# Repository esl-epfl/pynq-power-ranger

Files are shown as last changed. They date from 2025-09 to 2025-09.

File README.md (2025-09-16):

<div align="center">
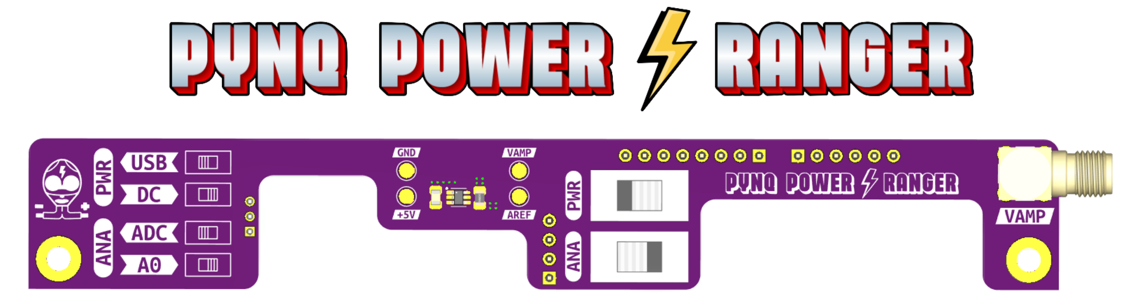
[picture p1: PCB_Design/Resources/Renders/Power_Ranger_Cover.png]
Power Ranger Board
    
</div>

## 🚀 Overview

The **Pynq Power Ranger** is a shield designed for the Xilinx Pynq-Z2 SoC board, enabling real-time power consumption measurement of the entire board. The repository contains the necessary PCB files to manufacture the power measurement shield together with the IP configuration to control the current measurement from Linux running on the processing system. The shield measures the voltage drop across a shunt resistor placed in series with the Pynq-Z2 power supply line using the ADC of the FPGA chip.

## 📦 Repository Contents
- **[Software Support](SW_Examples/README.md)**: The IP and driver to measure the current from the processing system and one application example that uses the Pynq Power Ranger to compute the energy consumption.
- **[Schematics & PCB](PCB_Design/README.md)**: A description of the board design and the KiCad files for board design, production, and hand/PnP assembly.

## ⚙️ Features

### ⚡ Selectable Input Power Supply
The switch **SW1 (PWR)** selects the power source of the Pynq-Z2 board:
- **Left**: The USB Micro-B Connector (5.0 V)
- **Right**: The DC Jack (7.0 V - 15.0 V, post-regulated to 5.0 V)

> [!WARNING]
> This switch replaces the jumper of the board. If the correct source is not selected, the board will not power up.

### 🎯 Selectable ADC Input Range and Precision
Use **SW2 (ANA)** to toggle between the inputs:
- **Left**: Specialized pin of the XADC of the chip (VP) -> Used by the Software Support examples
- **Right**: An alternative Arduino A0 pin. Internally connected to a 3:1 resistor voltage divider that outputs (1.0 V when the input voltage is 3.3 V). This allows for a wider input range at the cost of resolution.

<div align="center">

| Input Pin | Saturation Point | Resolution |
|---|---|---|
| VP | 1.25 A | 0.3 mA |
| A0 | 3.75 A | 1.0 mA |

</div>

> [!WARNING]
> The onboard ADC of the Pynq-Z2 board has a reference voltage of 1.0 V, which defines the saturation point of the measurement. If the current exceeds this value, the measurement will saturate and will not be accurate.

### 🧵 Thread-based Measurements
The software examples provided in this repository use a thread-based approach to continuously monitor the current consumption to accurately estimate energy consumption. This allows for real-time data acquisition and processing without blocking the main application.

## Contact
For additional information, please contact the authors:
- **Alex López**: [alejandro.lopezrodriguez@epfl.ch](mailto:alejandro.lopezrodriguez@epfl.ch)
- **Rubén Rodríguez**: [ruben.rodriguezalvarez@epfl.ch](mailto:ruben.rodriguezalvarez@epfl.ch)
- **Miguel Peón**: [miguel.peon@epfl.ch](mailto:miguel.peon@epfl.ch)

Developed at the **[Embedded Systems Laboratory (ESL), EPFL](https://www.epfl.ch/labs/esl/research/)**.

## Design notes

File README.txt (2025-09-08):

This folder contains two use examples for the Pynq Power Ranger, used with the Pynq Z2 board (TUL).

The Pynq Power Ranger is connected to the processors thru the AXI4 bus. To simplify integration in other projects, a file "recreate_xadc.tcl" is provided to include and configure the XADC module in a block diagram in Vivado.

All the examples are for execution with Vitis HLS and Vivado 2022.2.

The examples include also the SW necessary to create a C/C++ application in Linux, inside the Pynq board. The SW examples are meant to be compiled inside the Pynq board!

The HW projects include a Makefile with multiple targets through the Vitis HLS to Vivado and, finally, bitstream generation. Use 'make help' to display the list of available targets.

The bitstreams can be programmed directly from the Pynq board itself using the provided 'programOverlay.py' script. The script requires the '.bit' and '.hwh' files generated by Vivado. It's possible to generate the corresponding '.bin' files using bootgen to program the FPGA directly using the fpga_manager module.

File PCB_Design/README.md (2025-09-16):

# PCB Design for Pynq Power Ranger

<div align="center">
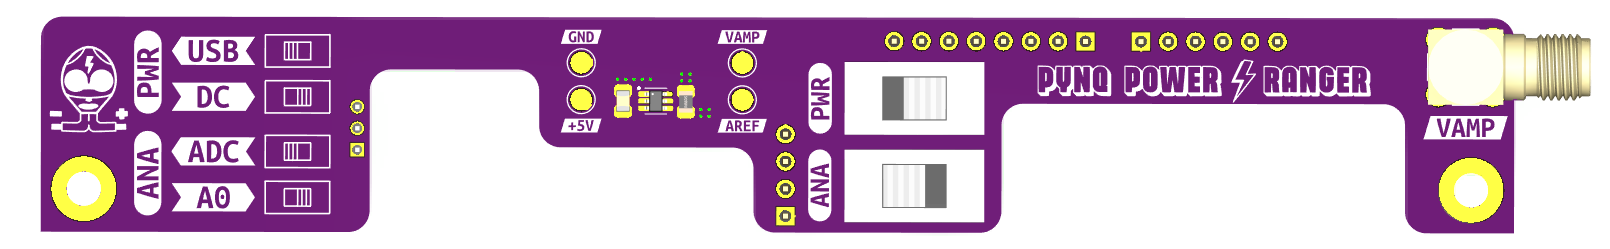
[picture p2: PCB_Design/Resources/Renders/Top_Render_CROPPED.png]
GSR Monitor Board
    
</div>

## 🚀 Description

This folder contains all the necessary files to manufacture the Pynq Power Ranger board. The design has been created using [KiCad EDA](https://kicad.org/).

## 📁 Repository Contents

- **KiCad Project Files**: The complete KiCad project files for the Pynq Power Ranger board.
- **Gerber Files**: The Gerber files required for PCB manufacturing.
- **BOM (Bill of Materials)**: A comprehensive list of all components used in the design.
- **Schematic Diagrams**: The schematic diagrams of the Pynq Power Ranger board.
- **PCB Layout**: The PCB layout files showing the physical arrangement of components and traces.

## 🔧 Design Overview

The board implements the following functionalities:
- A **shunt resistor** for current sensing.
- A **precision transimpedance amplifier** (INA214) to amplify the voltage drop across the shunt resistor.
- An ADC input connected to the FPGA's **XADC module** for voltage measurement.
- A **selectable input range** using a switch to choose between two different ADC input pins (VP and Arduino A0).
- A **power supply selection** switch to choose between USB and DC jack input for the Pynq-Z2 board.
- An **SMA connector** for direct voltage measurement with an oscilloscope.

### Input Range and Resolution
- **Arduino-compatible pins**: Internally connected to a resistor voltage divider that outputs **1.0 V when the input voltage is 3.3 V**. This allows for a wider input range at the cost of resolution.
- **VP pin**: Directly connected to the ADC input, providing better resolution but a lower range.

The amplifier has a **gain of 100 V/V**, and the **shunt resistor is 8 mΩ**. Thus, the INA214 output voltage is:

$$ V_{INA} = (I_{LOAD} \times 0.008 \ \Omega) \times 100 \text{ V/V} $$

- **For the VP pin ($V_{VP} = V_{INA}$)**, saturation occurs at $I_{LOAD}$ = 1.25 A ($V_{INA} = V_{ADC \ REF}$ = 1.0 V).

>[!CAUTION]
> If higher currents are required (e.g., for powering external PMODs), switch to **A0 mode**.

The output of the transimpedance amplifier is also routed to the SMA connector on the right side of the board, enabling a direct connection to an oscilloscope with high input impedance.

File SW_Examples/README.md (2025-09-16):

# Software Support for Pynq Power Ranger

## 🚀 Description

This folder contains two use examples that use the Pynq Power Ranger to measure the energy consumption of the Pynq Z2 board (TUL). Each example includes:
- The **[XADC IP configuration](Basic_Monitoring_SW_Power/HW/recreate_xadc.tcl)** to read the current measurement from the pin VP of the Power Ranger board. This IP is connected to the AXI4 bus to be controlled from the processing system.
- A **[C Proxy driver](Basic_Monitoring_SW_Power/SW/src/CXADCProxy.cpp)** to interface with the XADC IP from a Linux application. The XADC acquires 256 samples and averages them to deliver one sample at ~123 Hz. The worker thread waits 8130 us between sample readings (polling), which roughly matches the sample production rate of the ADC.

> [!NOTE]
> These examples assume that the Power Ranger is set to measure from the VP pin and the power is supplied from the USB connector with a typical input supply of 5V. 

## 📁 Contents
This folder contains two examples:
- **[Basic Monitoring](Basic_Monitoring_SW_Power)**: A more advanced example that continuously monitors the current consumption and logs the data to a file.
- **[Moving Average](ExampleMovingAvg)**: An example that applies a moving average filter to the current measurements to smooth out fluctuations.

To simplify integration in other projects, the **XADC IP Configuration and implementation** is provided in each example through the file "[recreate_xadc.tcl](Basic_Monitoring_SW_Power/HW/recreate_xadc.tcl)". This file is used to include and configure the XADC module in a block diagram in Vivado.

On each example there are two folders:
- **HW**: The Vivado project to generate the bitstream with the XADC IP. It include a Makefile with multiple targets for the project and bitstream generation. Use 'make help' to display the list of available targets.
- **SW**: The SW necessary to create a C/C++ application in Linux, inside the Pynq board. The application implements a driver to communicate with the XADC IP and read the current consumption. These SW examples are meant to be compiled inside the Pynq board!

> [!NOTE]
> All the examples are for execution with Vitis HLS and Vivado 2022.2.

## 🏃‍♂️ How to Run

Follow these steps to run the examples on your Pynq board:

### 1. Bitstream Generation
Go to the HW folder in a PC with Vivado installed, and generate the bitstream using the provided Makefile:
```bash
make bitstream
```

A .bit and .hwh files will be generated in the folder HW folder. These files are needed to program the FPGA in the Pynq board.

### 2. Bitstream Configuration
There are several alternatives to program the FPGA with the generated bitstream:
- Using the Vivado GUI, by opening the generated project and programming the FPGA directly. Open the HW Manager, connect to the board and program the FPGA with the generated .bit file.
- Directly from the Pynq board itself using the provided '[programOverlay.py](Basic_Monitoring_SW_Power/SW/programOverlay.py)' script. The script requires the '.bit' and '.hwh' files generated by Vivado. Copy the generated '.bit' and '.hwh' files to the Pynq board and run `sudo -E ./programOverlay.py <path_to_.bit>`.  
- Using the Pynq framework (Jupyter Notebooks). Copy the generated '.bit' and '.hwh' files to the Pynq board and refer to [Loading and Overlay](https://pynq.readthedocs.io/en/latest/pynq_overlays/loading_an_overlay.html) for more information on how to load an overlay.
- Using the fpga_manager module in Linux (fpgautil). For this, you need to generate the corresponding '.bin' files from the .bit using bootgen. Then run `sudo fpgautil -b <path_to_.bin>`.
- using the fpga_manager module manually. Copy the generated '.bit' file to the Pynq board and run the following as sudo:
```bash
echo 0 > /sys/class/fpga_manager/fpga0/flags
mkdir -p /lib/firmware
cp bitstream/accel_v$acc/design_1.bit.bin /lib/firmware/
echo <path_to_.bin> > /sys/class/fpga_manager/fpga0/firmware # Load bitstream
```

### 3. Run the Application
Copy the SW folder in the Pynq board running Linux. Then compile and run the application using the provided Makefile:
```bash
make
./PowerRanger # or ./testMovingAvg for the moving average example
```

## 🖥️ Basic Monitoring

Live monitoring of the current consumption is implemented in this example. The application reads the current consumption from the XADC IP every second and prints the value of power and energy to the console. If run in parallel with a benchmark application, it can be used to measure the energy consumption of the benchmark.

> [!WARNING]
> It will only work if the XADC IP is configured as in the example folder, if the bitstream is overwritten the program wont be able to communicate with the XADC.

## 🧮 Moving Average Filter

This example demonstrates an HLS implementation of a moving average filter with a window size of 7 samples. The application evaluates performance by measuring execution time and energy consumption when processing 8 million samples using three approaches: (i) a standard software version, (ii) an optimized software version, and (iii) a hardware version generated with HLS. The results are printed to the console. In summary, this example illustrates how to integrate power measurements into an application using the XADC proxy driver.

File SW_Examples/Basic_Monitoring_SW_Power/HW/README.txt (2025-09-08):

To recreate the bitstream, use the Makefile in this folder:

$ make help
  Prints make targets.
$ make vivado_project
  Generates the example Vivado project for the Pynq Z2 board, including the XADC connected to the AXI4 bus.
$ make bitstream
  Generates the Vivado project and synthesizes the bitstream.

------------------

To add the XADC module to an existing Vivado project, copy the contents of file "recreate_xadc.tcl" in Vivado's TCL console. Alternatively, run the script from the console.

------------------

The SW folder contains the SW modules necessary to read the XADC from an application running on the Pynq Z2 board.

The example application reads the instantaneous power from the XADC module and prints it on the console continuously. The application also reads the (accumulated) energy consumed since the application start.

If an application is run alongside in a different terminal, it will be possible to assess the increase of power required by the board while running that application, compared to an idle state, and the accumulated energy (since the start of the monitoring application).

-----------------
For more complex use cases, or in systems that include new hardware in the programmable logic, see the examples on integrating the XADC with a HW accelerator.

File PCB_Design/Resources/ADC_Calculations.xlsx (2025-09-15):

 |  |  |  | R_SHUNT | 0.008
 |  |  |  | GAIN | 100
 |  |  |  | V_REF | 0
I_LOAD | V_OUT | ADC 1 (V_REF = 1V) | ADC 2 (V_REF = 3,3V)
0 | 0 |  |  | ADC RES (bits) | 12 | Resolution 1 (mA)
0.05 | 0.04 |  |  | ADC 1 V_REF | 1 | 0.3051757812
0.1 | 0.08 |  |  | ADC 2 V_REF | 3.3
0.15 | 0.12 |  |  |  |  | Resolution 2 (mA)
0.2 | 0.16 |  |  |  |  | 1.007080078
0.25 | 0.2
0.3 | 0.24
0.35 | 0.28
0.4 | 0.32
0.45 | 0.36
0.5 | 0.4
0.55 | 0.44
0.6 | 0.48
0.65 | 0.52
0.7 | 0.56
0.75 | 0.6
0.8 | 0.64
0.85 | 0.68
0.9 | 0.72
0.95 | 0.76
1 | 0.8
1.05 | 0.84
1.1 | 0.88
1.15 | 0.92
1.2 | 0.96
1.25 | 1
1.3 | 1.04
1.35 | 1.08
1.4 | 1.12
1.45 | 1.16
1.5 | 1.2
1.55 | 1.24
1.6 | 1.28
1.65 | 1.32
1.7 | 1.36
1.75 | 1.4
1.8 | 1.44
1.85 | 1.48

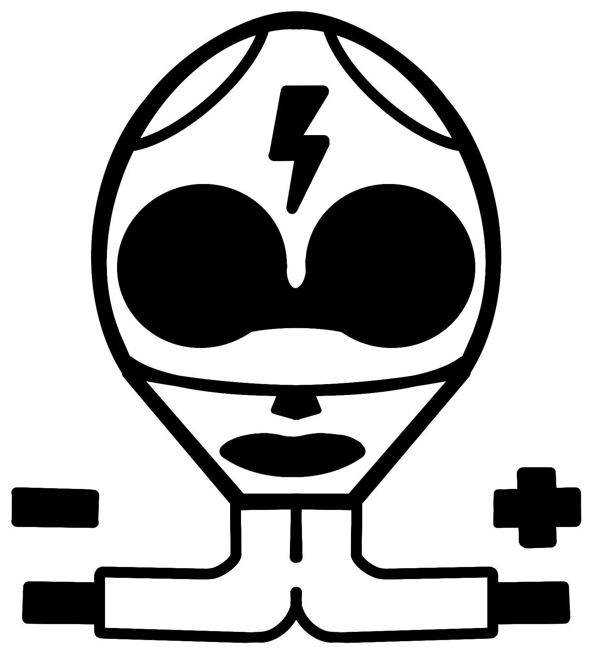
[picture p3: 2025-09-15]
PCB_Design/Resources/Graphics/Power_Ranger.png

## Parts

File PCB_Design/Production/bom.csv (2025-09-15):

Designator | Footprint | Quantity | Value | LCSC Part #
C1 | C0805 | 1 | 100n 10V | C2168659
J1 | 4-Row_Header_2.54mm | 1 | HB-PH3-25414PB2GOP | C6332197
J3 | 6-Row_Header_2.54mm | 1 | HB-PH3-25416PB2GOP | C6332199
J4 | 8-Row_Header_2.54mm | 1 | HB-PH3-25418PB2GOP | C6332201
R1 | R0805 | 1 | 0R008 | C728269
SW1, SW2 | SS-12D10L5 | 2 | SS-12D10L5 | C319012
U1 | SC70-6 | 1 | INA214AIDCKT | C105240

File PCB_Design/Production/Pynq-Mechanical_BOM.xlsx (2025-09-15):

Mouser MPN' | 'Qty' | 'Description' | 'Datasheet'
971120321 | 150 | Standoffs & Spacers WA-SSTIE M M 3x12mm SW 5.5 | https://www.we-online.com/components/products/datasheet/971120321.pdf
9191-2 | 150 | Screws & Fasteners METRIC COMBO SCREW RED | https://www.mouser.es/datasheet/2/215/191-2_9191-7-743372.pdf
ESQT-103-02-F-S-309 | 75 | 'Headers & Wire Housings FleXYZ Flexible-Height Socket Strip, 2.00mm Pitch' | 'https://www.mouser.es/datasheet/2/527/esqt_th-2854210.pdf'
LCSC MPN' | 'Qty' | 'Description' | 'Datasheet'
C357432 | 150 | M3 Hex Nut 0.217" (5.51mm) | https://www.lcsc.com/product-detail/Nut_Shuntian-DIN934-M3nie_C357432.html
C1509232 | 10 | SMA Right Angle Connector | https://www.lcsc.com/datasheet/lcsc_datasheet_2410010002_HJ-Tech-HJ-SMA017_C1509232.pdf

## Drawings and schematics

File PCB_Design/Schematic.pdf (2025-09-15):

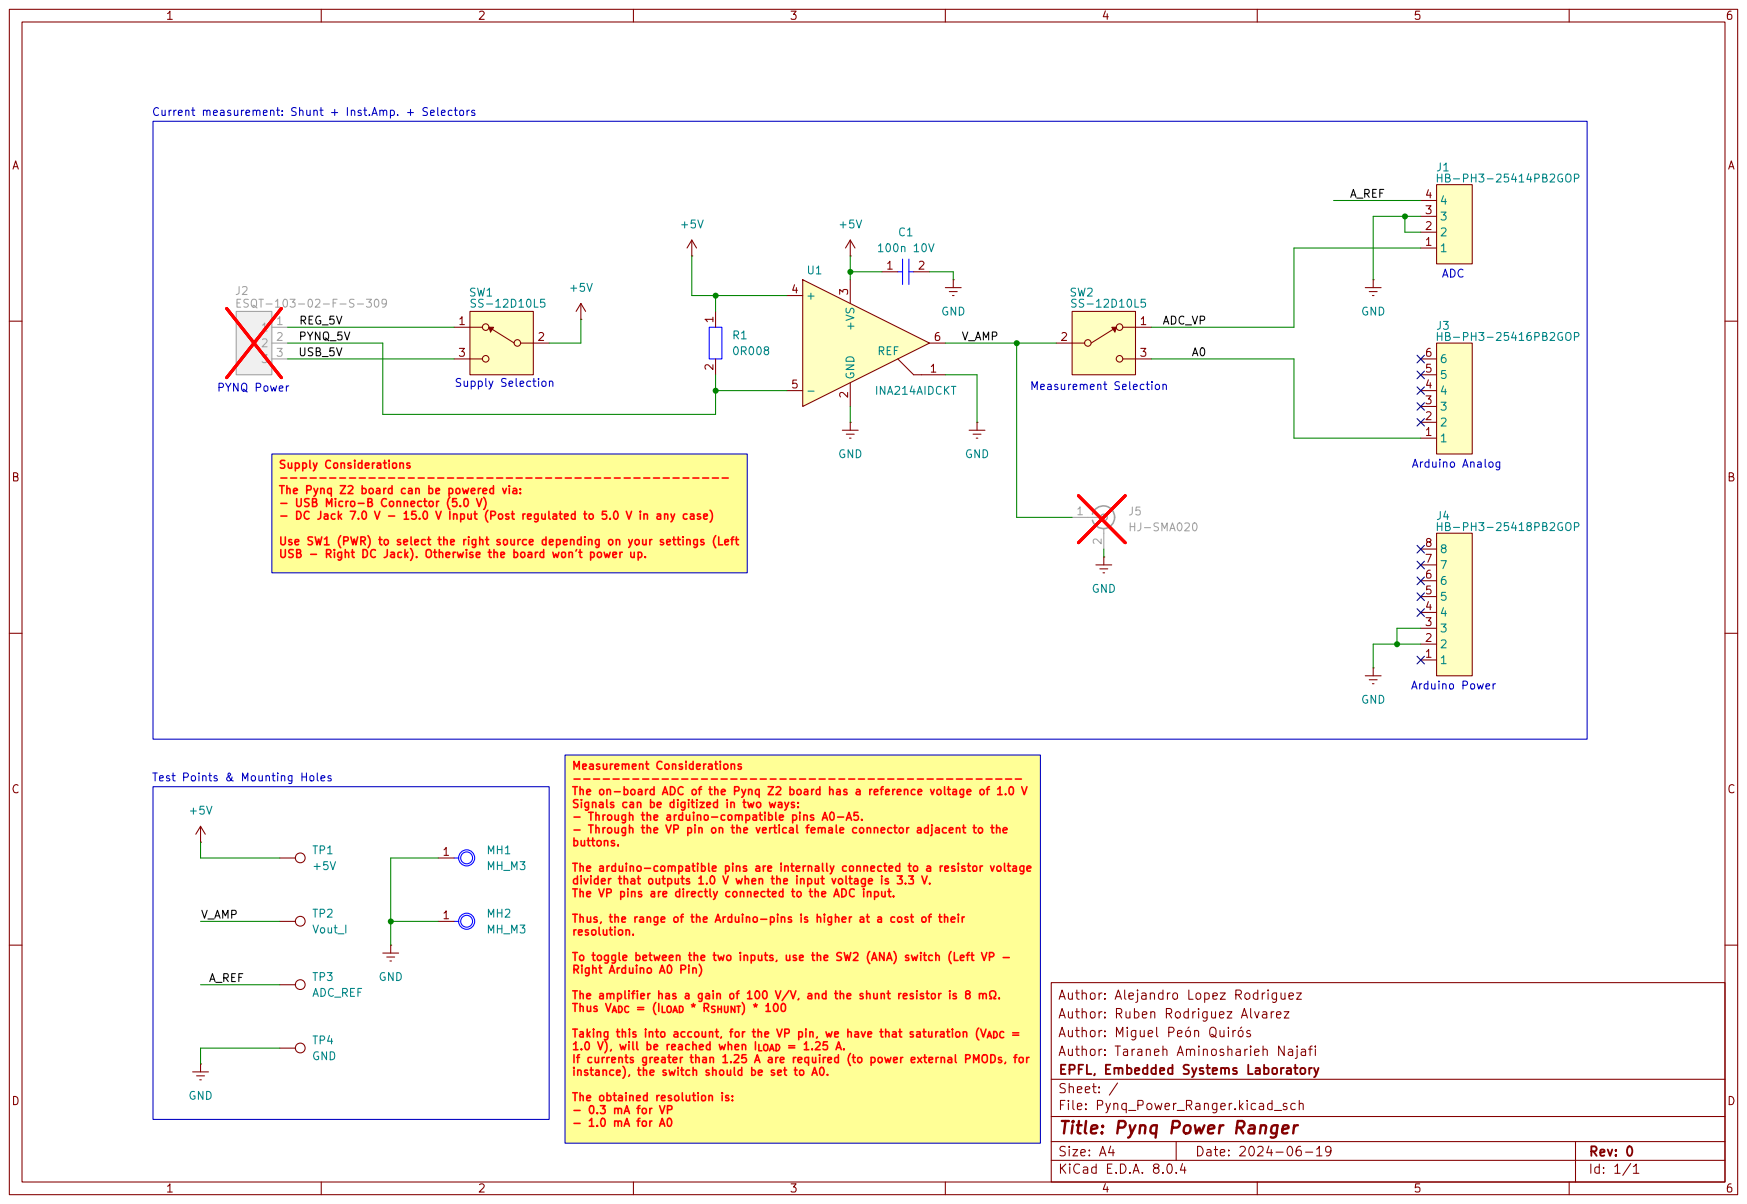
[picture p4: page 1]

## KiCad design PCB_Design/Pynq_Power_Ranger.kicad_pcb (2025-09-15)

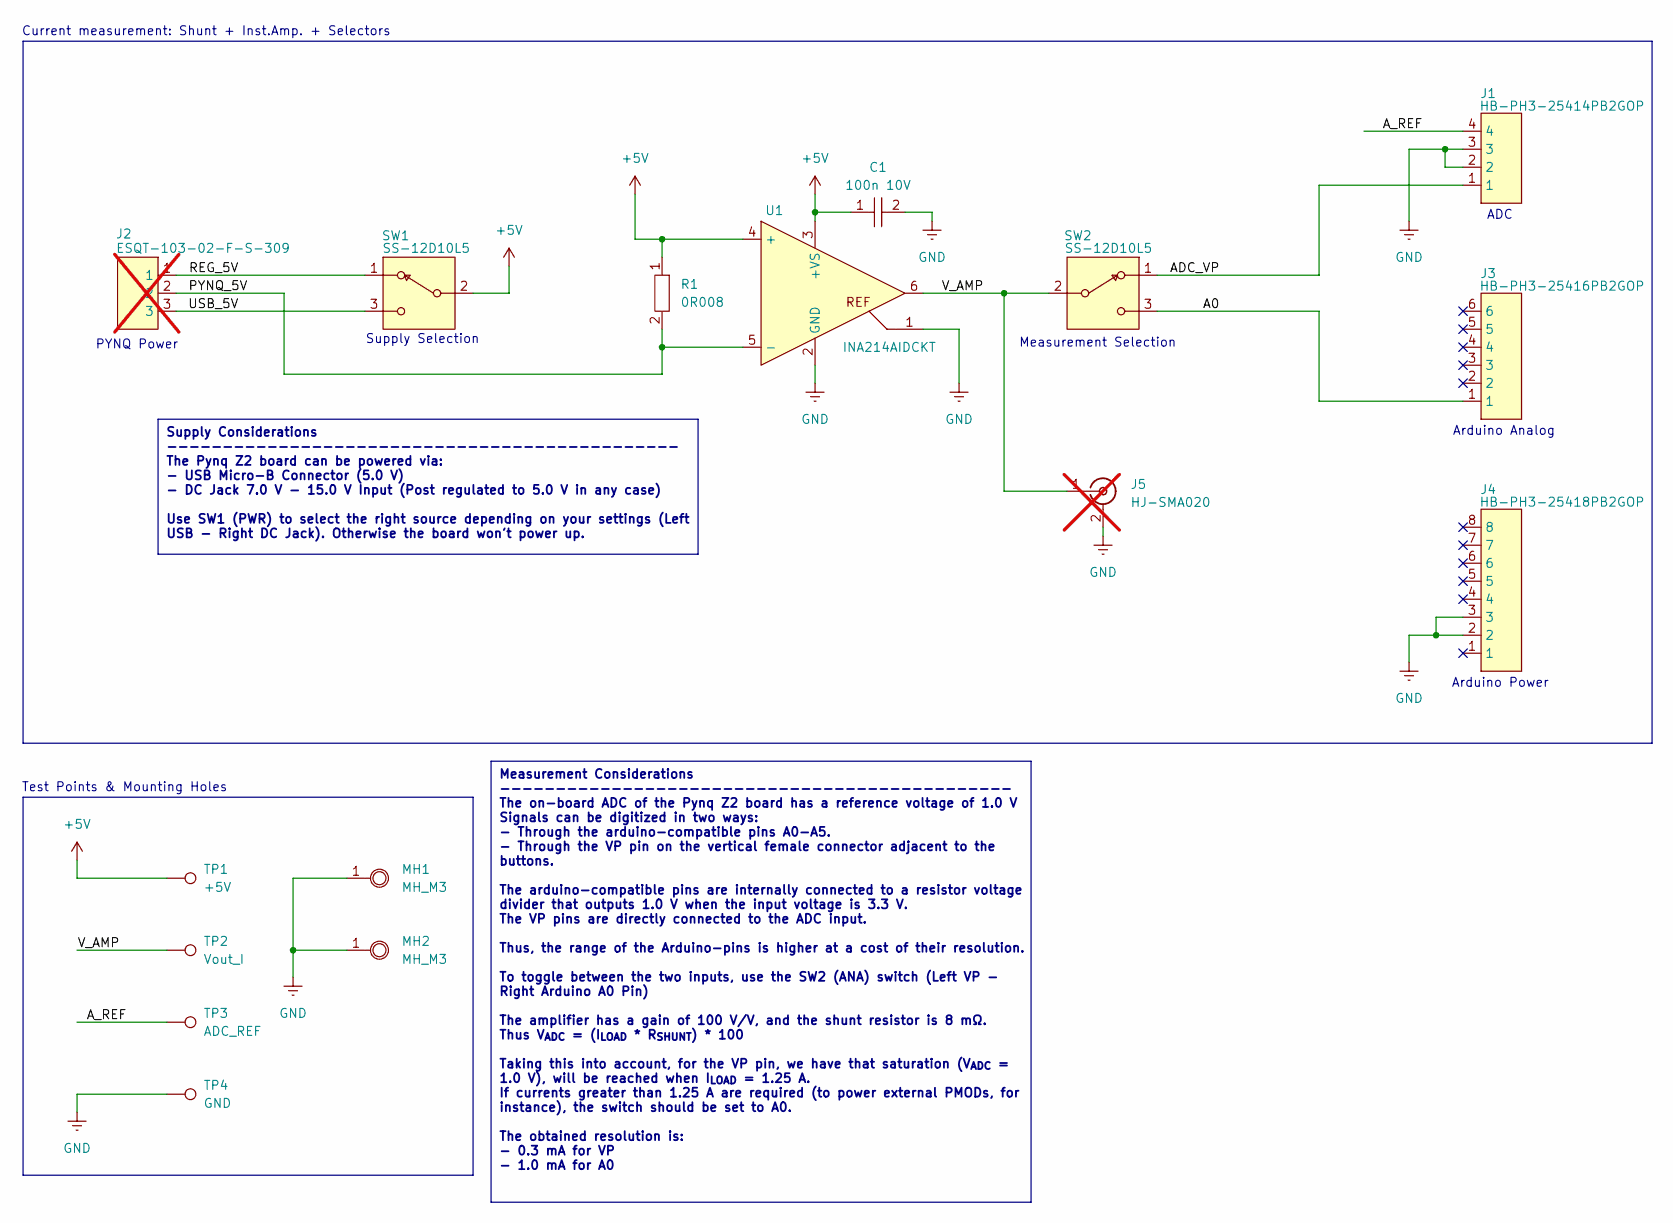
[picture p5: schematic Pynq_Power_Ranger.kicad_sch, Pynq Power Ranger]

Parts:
C1: 100n 10V; C0805; MPN C0805C104M3RACTU; LCSC C2168659
J1: HB-PH3-25414PB2GOP; 4-Row_Header_2.54mm; MPN HB-PH3-25414PB2GOP; LCSC C6332197
J2: ESQT-103-02-F-S-309; MPN ESQT-103-02-F-S-309; not fitted
J3: HB-PH3-25416PB2GOP; 6-Row_Header_2.54mm; MPN HB-PH3-25416PB2GOP; LCSC C6332199
J4: HB-PH3-25418PB2GOP; 8-Row_Header_2.54mm; MPN HB-PH3-25418PB2GOP; LCSC C6332201
J5: HJ-SMA020; MPN HJ-SMA020; LCSC C1509232; not fitted
MH1, MH2: MH_M3
R1: 0R008; R0805; MPN PA0805FRE470R008L; LCSC C728269
SW1, SW2: SS-12D10L5; MPN SS-12D10L5; LCSC C319012
TP1: +5V; TestPoint_Pad_D2.0mm
TP2: Vout_I; TestPoint_Pad_D2.0mm
TP3: ADC_REF; TestPoint_Pad_D2.0mm
TP4: GND; TestPoint_Pad_D2.0mm
U1: INA214AIDCKT; SC70-6; MPN INA214AIDCKT; LCSC C105240

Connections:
+5V: C1.1, R1.1, SW1.2, TP1.1, U1.3 (+VS), U1.4 (+)
/A0: J3.1, SW2.3
/ADC_VP: J1.1, SW2.1
/A_REF: J1.4, TP3.1
/PYNQ_5V: J2.2, R1.2, U1.5 (-)
/REG_5V: J2.1, SW1.1
/USB_5V: J2.3, SW1.3
/V_AMP: J5.1, SW2.2, TP2.1, U1.6
GND: C1.2, J1.2, J1.3, J4.2, J4.3, J5.2, MH1.1, MH2.1, TP4.1, U1.1, U1.2 (GND)

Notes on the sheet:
Supply Considerations ---------------------------------------------- The Pynq Z2 board can be powered via: - USB Micro-B Connector (5.0 V) - DC Jack 7.0 V - 15.0 V Input (Post regulated to 5.0 V in any case) Use SW1 (PWR) to select the right source depending on your settings (Left USB - Right DC Ja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
Measurement Considerations ---------------------------------------------- The on-board ADC of the Pynq Z2 board has a reference voltage of 1.0 V Signals can be digitized in two ways: - Through the arduino-compatible pins A0-A5. - Through the VP pin on the vertical female connector adjacent to the b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
Arduino Power
Current measurement: Shunt + Inst.Amp. + Selectors
ADC
Arduino Analog
Measurement Selection
Supply Selection
Test Points & Mounting Holes
PYNQ Power

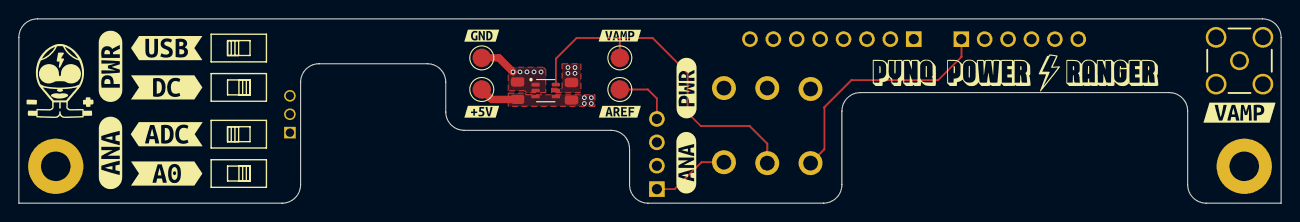
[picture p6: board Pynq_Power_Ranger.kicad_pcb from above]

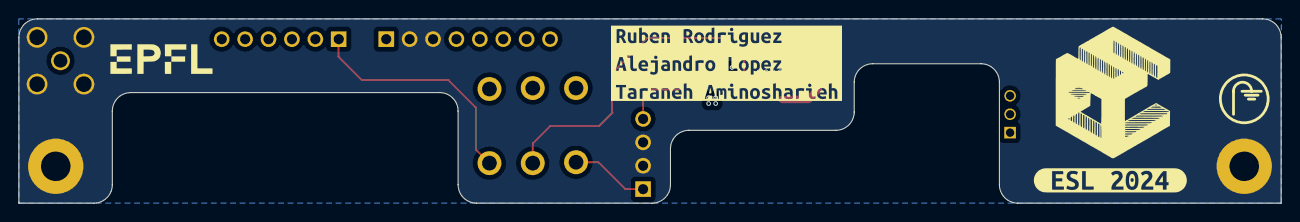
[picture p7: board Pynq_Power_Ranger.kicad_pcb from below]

Board: 4 copper layers, 137.0 x 20.0 mm, 31 parts (5 on the bottom side), 9 nets.

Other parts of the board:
kibuzzard-68C055AF: G***; kibuzzard-68C055AF
kibuzzard-68C055B7: G***; kibuzzard-68C055B7
kibuzzard-6703B37F: G***; kibuzzard-6703B37F
kibuzzard-6703B435: G***; kibuzzard-6703B435
kibuzzard-67001D02: G***; kibuzzard-67001D02
kibuzzard-67001D4B: G***; kibuzzard-67001D4B
kibuzzard-67001D32: G***; kibuzzard-67001D32
kibuzzard-67001D54: G***; kibuzzard-67001D54
kibuzzard-67001FBD: G***; kibuzzard-67001FBD
kibuzzard-67001FE8: G***; kibuzzard-67001FE8
kibuzzard-67080F4D: G***; kibuzzard-67080F4D
kibuzzard-670020E4: G***; kibuzzard-670020E4
kibuzzard-6700203E: G***; kibuzzard-6700203E
kibuzzard-67002037: G***; kibuzzard-67002037
kibuzzard-67002108: G***; kibuzzard-67002108

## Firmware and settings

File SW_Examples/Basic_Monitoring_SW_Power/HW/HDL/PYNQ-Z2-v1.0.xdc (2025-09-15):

## This file is a general .xdc for the PYNQ-Z2 board 
## To use it in a project:
## - uncomment the lines corresponding to used pins
## - rename the used ports (in each line, after get_ports) according to the top level signal names in the project

## Clock signal 125 MHz

#set_property -dict { PACKAGE_PIN H16   IOSTANDARD LVCMOS33 } [get_ports { sysclk }]; #IO_L13P_T2_MRCC_35 Sch=sysclk
#create_clock -add -name sys_clk_pin -period 8.00 -waveform {0 4} [get_ports { sysclk }];

##Switches

#set_property -dict { PACKAGE_PIN M20   IOSTANDARD LVCMOS33 } [get_ports { sw[0] }]; #IO_L7N_T1_AD2N_35 Sch=sw[0]
#set_property -dict { PACKAGE_PIN M19   IOSTANDARD LVCMOS33 } [get_ports { sw[1] }]; #IO_L7P_T1_AD2P_35 Sch=sw[1]

##RGB LEDs

#set_property -dict { PACKAGE_PIN L15   IOSTANDARD LVCMOS33 } [get_ports { led4_b }]; #IO_L22N_T3_AD7N_35 Sch=led4_b
#set_property -dict { PACKAGE_PIN G17   IOSTANDARD LVCMOS33 } [get_ports { led4_g }]; #IO_L16P_T2_35 Sch=led4_g
#set_property -dict { PACKAGE_PIN N15   IOSTANDARD LVCMOS33 } [get_ports { led4_r }]; #IO_L21P_T3_DQS_AD14P_35 Sch=led4_r
#set_property -dict { PACKAGE_PIN G14   IOSTANDARD LVCMOS33 } [get_ports { led5_b }]; #IO_0_35 Sch=led5_b
#set_property -dict { PACKAGE_PIN L14   IOSTANDARD LVCMOS33 } [get_ports { led5_g }]; #IO_L22P_T3_AD7P_35 Sch=led5_g
#set_property -dict { PACKAGE_PIN M15   IOSTANDARD LVCMOS33 } [get_ports { led5_r }]; #IO_L23N_T3_35 Sch=led5_r

##LEDs

#set_property -dict { PACKAGE_PIN R14   IOSTANDARD LVCMOS33 } [get_ports { led[0] }]; #IO_L6N_T0_VREF_34 Sch=led[0]
#set_property -dict { PACKAGE_PIN P14   IOSTANDARD LVCMOS33 } [get_ports { led[1] }]; #IO_L6P_T0_34 Sch=led[1]
#set_property -dict { PACKAGE_PIN N16   IOSTANDARD LVCMOS33 } [get_ports { led[2] }]; #IO_L21N_T3_DQS_AD14N_35 Sch=led[2]
#set_property -dict { PACKAGE_PIN M14   IOSTANDARD LVCMOS33 } [get_ports { led[3] }]; #IO_L23P_T3_35 Sch=led[3]

##Buttons

#set_property -dict { PACKAGE_PIN D19   IOSTANDARD LVCMOS33 } [get_ports { btn[0] }]; #IO_L4P_T0_35 Sch=btn[0]
#set_property -dict { PACKAGE_PIN D20   IOSTANDARD LVCMOS33 } [get_ports { btn[1] }]; #IO_L4N_T0_35 Sch=btn[1]
#set_property -dict { PACKAGE_PIN L20   IOSTANDARD LVCMOS33 } [get_ports { btn[2] }]; #IO_L9N_T1_DQS_AD3N_35 Sch=btn[2]
#set_property -dict { PACKAGE_PIN L19   IOSTANDARD LVCMOS33 } [get_ports { btn[3] }]; #IO_L9P_T1_DQS_AD3P_35 Sch=btn[3]

##PmodA

#set_property -dict { PACKAGE_PIN Y18   IOSTANDARD LVCMOS33 } [get_ports { ja[0] }]; #IO_L17P_T2_34 Sch=ja_p[1]
#set_property -dict { PACKAGE_PIN Y19   IOSTANDARD LVCMOS33 } [get_ports { ja[1] }]; #IO_L17N_T2_34 Sch=ja_n[1]
#set_property -dict { PACKAGE_PIN Y16   IOSTANDARD LVCMOS33 } [get_ports { ja[2] }]; #IO_L7P_T1_34 Sch=ja_p[2]
#set_property -dict { PACKAGE_PIN Y17   IOSTANDARD LVCMOS33 } [get_ports { ja[3] }]; #IO_L7N_T1_34 Sch=ja_n[2]
#set_property -dict { PACKAGE_PIN U18   IOSTANDARD LVCMOS33 } [get_ports { ja[4] }]; #IO_L12P_T1_MRCC_34 Sch=ja_p[3]
#set_property -dict { PACKAGE_PIN U19   IOSTANDARD LVCMOS33 } [get_ports { ja[5] }]; #IO_L12N_T1_MRCC_34 Sch=ja_n[3]
#set_property -dict { PACKAGE_PIN W18   IOSTANDARD LVCMOS33 } [get_ports { ja[6] }]; #IO_L22P_T3_34 Sch=ja_p[4]
#set_property -dict { PACKAGE_PIN W19   IOSTANDARD LVCMOS33 } [get_ports { ja[7] }]; #IO_L22N_T3_34 Sch=ja_n[4]

##PmodB

#set_property -dict { PACKAGE_PIN W14   IOSTANDARD LVCMOS33 } [get_ports { jb[0] }]; #IO_L8P_T1_34 Sch=jb_p[1]
#set_property -dict { PACKAGE_PIN Y14   IOSTANDARD LVCMOS33 } [get_ports { jb[1] }]; #IO_L8N_T1_34 Sch=jb_n[1]
#set_property -dict { PACKAGE_PIN T11   IOSTANDARD LVCMOS33 } [get_ports { jb[2] }]; #IO_L1P_T0_34 Sch=jb_p[2]
#set_property -dict { PACKAGE_PIN T10   IOSTANDARD LVCMOS33 } [get_ports { jb[3] }]; #IO_L1N_T0_34 Sch=jb_n[2]
#set_property -dict { PACKAGE_PIN V16   IOSTANDARD LVCMOS33 } [get_ports { jb[4] }]; #IO_L18P_T2_34 Sch=jb_p[3]
#set_property -dict { PACKAGE_PIN W16   IOSTANDARD LVCMOS33 } [get_ports { jb[5] }]; #IO_L18N_T2_34 Sch=jb_n[3]
#set_property -dict { PACKAGE_PIN V12   IOSTANDARD LVCMOS33 } [get_ports { jb[6] }]; #IO_L4P_T0_34 Sch=jb_p[4]
#set_property -dict { PACKAGE_PIN W13   IOSTANDARD LVCMOS33 } [get_ports { jb[7] }]; #IO_L4N_T0_34 Sch=jb_n[4]

##Audio 

#set_property -dict { PACKAGE_PIN M17   IOSTANDARD LVCMOS33 } [get_ports { adr0 }]; #IO_L8P_T1_AD10P_35 Sch=adr0
#set_property -dict { PACKAGE_PIN M18   IOSTANDARD LVCMOS33 } [get_ports { adr1 }]; #IO_L8N_T1_AD10N_35 Sch=adr1
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

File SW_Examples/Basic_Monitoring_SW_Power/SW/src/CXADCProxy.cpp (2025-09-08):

#include <stdio.h>
#include <stdlib.h>
#include <string.h>
#include <stdint.h>
#include <unistd.h>
#include <pthread.h>
#include <map>

#include "util.hpp"

#include "CAccelProxy.hpp"
#include "CXADCProxy.hpp"

///////////////////////////////////////////////////////////////////////////////
//         Threading control                                                  /
///////////////////////////////////////////////////////////////////////////////

///////////////////////////////////////////////////////////////////////////////
CXADCProxy::CXADCProxy(bool Logging, const char * ThreadName, uint32_t CPU)
  : CAccelProxy(Logging),
  threadID(-1), cpuNum(CPU), stopping(false), stoppingACK(true),
  accEnergy(0.0), lastPower(0.0)
{
  uint32_t nameLength;

  if (ThreadName != NULL) {
    nameLength = strlen(ThreadName) + 1;
    threadName = (char*)malloc(nameLength);
    if (threadName != NULL)
      strncpy(threadName, ThreadName, nameLength);
  }
  else {
    threadName = (char*)malloc(256);
    if (threadName != NULL)
      strncpy(threadName, "XADC_THREAD", 255);
  }
}


///////////////////////////////////////////////////////////////////////////////
CXADCProxy::~CXADCProxy()
{
  if (!stoppingACK)
    StopMeasurements();
  if (threadName != NULL) {
    free(threadName);
    threadName = NULL;
  }
}


///////////////////////////////////////////////////////////////////////////////
// This function is the entry point for new threads. It does not receive a this pointer.
// Therefore, we use the only argument as a pointer to an object of our class and call
// its Main() function from this new thread.
void * CXADCProxy::NewThread(void * objectPointer)
{
	((CXADCProxy *)objectPointer)->Main();
	return NULL;
}


///////////////////////////////////////////////////////////////////////////////
//         XADC interaction                                                   /
///////////////////////////////////////////////////////////////////////////////

///////////////////////////////////////////////////////////////////////////////
// Start measuring (accumulating) energy in a new thread.
bool CXADCProxy::StartMeasurements()
{
	int res;
	pthread_attr_t attributes;

  stoppingACK = false;
  accEnergy = 0.0;

	pthread_attr_init(&attributes);
	pthread_attr_setdetachstate(&attributes, PTHREAD_CREATE_JOINABLE);
	res = pthread_create((pthread_t*)&threadID, &attributes, NewThread, (void *)this);
	// The new thread goes to static NewThread() and then to
	// the Main() of the derived class. Here, just exit
	// and return to the caller.

	pthread_attr_destroy(&attributes);

  if (cpuNum != UINT32_MAX) {
  	cpu_set_t cpuset;
	  CPU_ZERO(&cpuset);
    CPU_SET(cpuNum, &cpuset);
	  pthread_setaffinity_np(threadID, sizeof(cpuset), &cpuset);
  }

	if (threadName != NULL)
		pthread_setname_np(threadID, threadName);

	return !res;
}

///////////////////////////////////////////////////////////////////////////////
// Stop acquiring power/energy samples. Exits the worker thread.
// This function blocks (sleeps) until the worker thread executes and reads
// the stopping flag.
bool CXADCProxy::StopMeasurements()
{
	int res = -1;

	if (!stoppingACK) {
		stopping = true;
		res = pthread_join(threadID, NULL); // Blocking!
	}
	return (res == 0);
}


///////////////////////////////////////////////////////////////////////////////
// This function runs in a separate thread, polling the XADC every ~10 ms.
bool CXADCProxy::Main()
{
  struct timespec before, now;

  if (logging)
	  printf("CXADCProxy entering Thread: %lu - \"%s\"\n", threadID, threadName);

  ResetXADC();
  clock_gettime(CLOCK_MONOTONIC_RAW, &before);
  usleep(SAMPLING_PERIOD_us);

	while (!stopping) {
    double power;

    clock_gettime(CLOCK_MONOTONIC_RAW, &now);
    power = GetPower();
    lastPower = (float)power; // Update it here so users can get also the power.

    accEnergy += power * CalcTimeDiff(now, before) / 1e9;
    before = now;
    usleep(SAMPLING_PERIOD_us);
	}

	stoppingACK = true;
  if (logging)
	  printf("CXADCProxy exiting Thread: %lu - \"%s\"\n", threadID, threadName);
	return true;
}


///////////////////////////////////////////////////////////////////////////////
void CXADCProxy::ResetXADC()
{
  volatile uint32_t * regs = (volatile uint32_t *)accelRegs;

  if (logging)
    printf("CXADCProxy::ResetXADC()\n");
  *(regs + R_SW_RESET) = 0x0000000A;
  usleep(1000);
}


///////////////////////////////////////////////////////////////////////////////
// Reads power measurement from the ADC.
// This function should not be called by the client once StartMeasurements() is called
// because it is not thread-safe and can lead to the XADC interface or the HW ADC itself crashing.
double CXADCProxy::GetPower()
{
  volatile uint32_t * regs = (volatile uint32_t *)accelRegs;
  uint32_t adc;

  // Wait EOC
  while ( ! (*(regs+R_STATUS) & 32) );

  adc = *(regs+R_VPVN_DATA);
  if (logging)
    printf("CXADCProxy::GetPower() Read: %u\n", adc);

  // Remove first the JTAG status bits on AXI bits 17 & 16 
  // (we assume there are no JTAG transactions in this system).
  // ADC gives 12 bits, left aligned on 15-4.
  adc = (adc & 0xFFFF) >> 4;

  return adc * ADC_GAIN_FACTOR * VCC;
}

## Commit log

2025-09-08 Adding initial examples for use of the Pynq Power Ranger.
2025-09-15 Added PCB files, gitignore, README.
    [ADC_Calculations.xlsx, Pynq-Mechanical_BOM.xlsx, Pynq_Power_Ranger.kicad_pcb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]
2025-09-16 Full documentation
    [ADC_Calculations.xlsx, Pynq-Mechanical_BOM.xlsx, Pynq_Power_Ranger.kicad_pcb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]
2025-09-16 Fix typo in the sample frequency
